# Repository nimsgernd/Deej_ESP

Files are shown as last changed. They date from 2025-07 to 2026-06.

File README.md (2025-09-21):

# Deej Fork by Daniel Nimsgern

Original deej project (description below) by omriharel

After this project sat idle for so long due to budget reasons I have decided to revive it. The main changes I am looking at are a custom PCB and a switch to using an ESP32 for ease of use and adding wireless capabilities.

The desired feature list is:
- 6 Slide potentiometers
- 6 Mute buttons (Cherry MX Green Switches)
- 2 Rotary potentiometers with switches
- 8 LED mute indicators
- 12 Slide poentiometer indicators
- 4 SPI 128x64 OLED displays

Ideas for a Rev2:
- Li-Ion battery powered (maybe 18650 or pouch cell)

# deej

deej is an **open-source hardware volume mixer** for Windows and Linux PCs. It lets you use real-life sliders (like a DJ!) to **seamlessly control the volumes of different apps** (such as your music player, the game you're playing and your voice chat session) without having to stop what you're doing.

**Join the [deej Discord server](https://discord.gg/nf88NJu) if you need help or have any questions!**



> **_New:_** [work-in-progress deej FAQ](./docs/faq/faq.md)!

deej consists of a [lightweight desktop client](#features) written in Go, and an Arduino-based hardware setup that's simple and cheap to build. [**Check out some versions built by members of our community!**](./community.md)

**[Download the latest release](https://github.com/omriharel/deej/releases/latest) | [Video demonstration](https://youtu.be/VoByJ4USMr8) | [Build video by Tech Always](https://youtu.be/x2yXbFiiAeI)**

deej

> _**Psst!** [No 3D printer? No problem!](./assets/build-shoebox.jpg)_ You can build deej on some cardboard, a shoebox or even a breadboard :)

## Table of contents

- [Deej Fork by Daniel Nimsgern](#deej-fork-by-daniel-nimsgern)
- [deej](#deej)
  - [Table of contents](#table-of-contents)
  - [Features](#features)
  - [How it works](#how-it-works)
    - [Hardware](#hardware)
      - [Schematic](#schematic)
    - [Software](#software)
  - [Slider mapping (configuration)](#slider-mapping-configuration)
  - [Build your own!](#build-your-own)
    - [FAQ](#faq)
    - [Build video](#build-video)
    - [Bill of Materials](#bill-of-materials)
    - [Thingiverse collection](#thingiverse-collection)
    - [Build procedure](#build-procedure)
  - [How to run](#how-to-run)
    - [Requirements](#requirements)
      - [Windows](#windows)
      - [Linux](#linux)
    - [Download and installation](#download-and-installation)
    - [Building from source](#building-from-source)
  - [Community](#community)
    - [Donations](#donations)
    - [Contributing](#contributing)
  - [License](#license)

## Features

deej is written in Go and [distributed](https://github.com/omriharel/deej/releases/latest) as a portable (no installer needed) executable.

- Bind apps to different sliders
  - Bind multiple apps per slider (i.e. one slider for all your games)
  - Bind the master channel
  - Bind "system sounds" (on Windows)
  - Bind specific audio devices by name (on Windows)
  - Bind currently active app (on Windows)
  - Bind all other unassigned apps
- Control your microphone's input level
- Lightweight desktop client, consuming around 10MB of memory
- Runs from your system tray
- Helpful notifications to let you know if something isn't working

> **Looking for the older Python version?** It's no longer maintained, but you can always find it in the [`legacy-python` branch](https://github.com/omriharel/deej/tree/legacy-python).

## How it works

### Hardware

- The sliders are connected to 5 (or as many as you like) analog pins on an Arduino Nano/Uno board. They're powered from the board's 5V output (see schematic)
- The board connects via a USB cable to the PC

#### Schematic

Hardware schematic

### Software

- The code running on the Arduino board is a [C program](./arduino/deej-5-sliders-vanilla/deej-5-sliders-vanilla.ino) constantly writing current slider values over its serial interface
- The PC runs a lightweight [Go client](./pkg/deej/cmd/main.go) in the background. This client reads the serial stream and adjusts app volumes according to the given configuration file

## Slider mapping (configuration)

deej uses a simple YAML-formatted configuration file named [`config.yaml`](./config.yaml), placed alongside the deej executable.

The config file determines which applications (and devices) are mapped to which sliders, and which parameters to use for the connection to the Arduino board, as well as other user preferences.

**This file auto-reloads when its contents are changed, so you can change application mappings on-the-fly without restarting deej.**

It looks like this:

```yaml
slider_mapping:
  0: master
  1: chrome.exe
  2: spotify.exe
  3:
    - pathofexile_x64.exe
    - rocketleague.exe
  4: discord.exe

# set this to true if you want the controls inverted (i.e. top is 0%, bottom is 100%)
invert_sliders: false

# settings for connecting to the arduino board
com_port: COM4
baud_rate: 9600

# adjust the amount of signal noise reduction depending on your hardware quality
# supported values are "low" (excellent hardware), "default" (regular hardware) or "high" (bad, noisy hardware)
noise_reduction: default
```

- `master` is a special option to control the master volume of the system _(uses the default playback device)_
- `mic` is a special option to control your microphone's input level _(uses the default recording device)_
- `deej.unmapped` is a special option to control all apps that aren't bound to any slider ("everything else")
- On Windows, `deej.current` is a special option to control whichever app is currently in focus
- On Windows, you can specify a device's full name, i.e. `Speakers (Realtek High Definition Audio)`, to bind that device's level to a slider. This doesn't conflict with the default `master` and `mic` options, and works for both input and output devices.
  - Be sure to use the full device name, as seen in the menu that comes up when left-clicking the speaker icon in the tray menu
- `system` is a special option on Windows to control the "System sounds" volume in the Windows mixer
- All names are case-**in**sensitive, meaning both `chrome.exe` and `CHROME.exe` will work
- You can create groups of process names (using a list) to either:
    - control more than one app with a single slider
    - choose whichever process in the group that's currently running (i.e. to have one slider control any game you're playing)

## Build your own!

Building deej is very simple. You only need a few relatively cheap parts - it's an excellent starter project (and my first Arduino project, personally). Remember that if you need any help or have a question that's not answered here, you can always [join the deej Discord server](https://discord.gg/nf88NJu).

Build deej for yourself, or as an awesome gift for your gaming buddies!

### FAQ

I've started a highly focused effort of writing a proper FAQ page for deej, covering many basic and advanced topics.

It is still _very much a work-in-progress_, but I'm happy to [share it in its current state](./docs/faq/faq.md) in hopes that it at least covers some questions you might have.

FAQ feedback in our [community Discord](https://discord.gg/nf88NJu) is strongly encouraged :)

### Build video

In case you prefer watching to reading, Charles from the [**Tech Always**](https://www.youtube.com/c/TechAlways) YouTube channel has made [**a fantastic video**](https://youtu.be/x2yXbFiiAeI) that covers the basics of building deej for yourself, including parts, costs, assembly and software. I highly recommend checking it out!

### Bill of Materials

- An Arduino Nano, Pro Micro or Uno board
  - I officially recommend using a Nano or a Pro Micro for their smaller form-factor, friendlier USB connectors and more analog pins. Plus they're cheaper
  - You can also use any other development board that has a Serial over USB interface
- A few slider potentiometers, up to your number of free analog pins (the cheaper ones cost around 1-2 USD each, and come with a standard 10K Ohm variable resistor. These _should_ work just fine for this project)
  - **Important:** make sure to get **linear** sliders, not logarithmic ones! Check the product description
  - You can also use circular knobs if you like
- Some wires
- Any kind of box to hold everything together. **You don't need a 3D printer for this project!** It works fantastically with just a piece of cardboard or a shoebox. That being said, if you do have one, read on...

### Thingiverse collection

With many different 3D-printed designs being added to our [community showcase](./community.md), it felt right to gather all of them in a Thingiverse collection for you to browse. If you have access to a 3D printer, feel free to use one of the designs in your build.

**[Visit our community-created design collection on Thingiverse!](https://thingiverse.com/omriharel/collections/deej)**

> You can also [submit your own](https://discord.gg/nf88NJu) design to be added to the collection. Regardless, if you do upload your design to Thingiverse, _please add a `deej` tag to it so that others can find it more easily_.

### Build procedure

- Connect everything according to the [schematic](#schematic)
- Test with a multimeter to be sure your sliders are hooked up correctly
- Flash the Arduino chip with the sketch in [`arduino\deej-5-sliders-vanilla`](./arduino/deej-5-sliders-vanilla/deej-5-sliders-vanilla.ino)
  - _Important:_ If you have more or less than 5 sliders, you must edit the sketch to match what you have
- After flashing, check the serial monitor. You should see a constant stream of values separated by a pipe (`|`) character, e.g. `0|240|1023|0|483`
  - When you move a slider, its corresponding value should move between 0 and 1023
- Congratulations, you're now ready to run the deej executable!

## How to run

### Requirements

#### Windows

- Windows. That's it

#### Linux

- Install `libgtk-3-dev`, `libappindicator3-dev` and `libwebkit2gtk-4.0-dev` for system tray support. Pre-built Linux binaries aren't currently released, so you'll need to [build from source](#building-from-source). If there's demand for pre-built binaries, please [let me know](https://discord.gg/nf88NJu)!

### Download and installation

- Head over to the [releases page](https://github.com/omriharel/deej/releases) and download the [latest version](https://github.com/omriharel/deej/releases/latest)'s executable and configuration file (`deej.exe` and `config.yaml`)
- Place them in the same directory anywhere on your machine
- (Optional, on Windows) Create a shortcut to `deej.exe` and copy it to `%APPDATA%\Microsoft\Windows\Start Menu\Programs\Startup` to have deej run on boot

### Building from source

If you'd rather not download a compiled executable, or want to extend deej or modify it to your needs, feel free to clone the repository and build it yourself. All you need is a Go 1.14 (or above) environment on your machine. If you go this route, make sure to check out the [developer scripts](./pkg/deej/scripts).

Like other Go packages, you can also use the `go get` tool: `go get -u github.com/omriharel/deej`. Please note that the package code now resides in the `pkg/deej` directory, and needs to be imported from there if used inside another project.

If you need any help with this, please [join our Discord server](https://discord.gg/nf88NJu).

## Community



deej is a relatively new project, but a vibrant and awesome community is rapidly growing around it. Come hang out with us in the [deej Discord server](https://discord.gg/nf88NJu), or check out a whole bunch of cool and creative builds made by our members in the [community showcase](./community.md).

The server is also a great place to ask questions, suggest features or report bugs (but of course, feel free to use GitHub if you prefer).

### Donations

If you love deej and want to show your support for this project, you can do so using the link below. Please don't feel obligated to donate - building the project and telling your friends about it goes a very long way! Thank you very much.



### Contributing

Please see [`docs/CONTRIBUTING.md`](./docs/CONTRIBUTING.md).

## License

deej is released under the [MIT license](./LICENSE).

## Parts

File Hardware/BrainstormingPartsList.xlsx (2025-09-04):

Part Name | Part ID | Qt. | Price | Sum | Octopart Link
Murata 0.1uF Capacitor | GCJ188R71H104KA12D | 18.00 | $0.12 | $2.16 | https://octopart.com/gcj188r71h104ka12d-murata-20842003
Murata 1uF Capacitor | GCM188R71E105KA64D | 1.00 | $0.19 | $0.19 | https://octopart.com/gcm188r71e105ka64d-murata-18909256
Murata 22uF Capacitor | GRM188R61A226ME15D | 1.00 | $0.11 | $0.11 | https://octopart.com/grm188r61a226me15d-murata-39203794
Murata 10uF Capacitor | GRM188D71A106MA73D | 2.00 | $0.26 | $0.52 | https://octopart.com/grm188d71a106ma73d-murata-26982325
Vishay 0.1uF Polarized Capacitor | 293D104X0035A2TE3 | 16.00 | $0.41 | $6.56 | https://octopart.com/293d104x0035a2te3-vishay-42464905
STM ESD Diode | ESDA25P35-1U1M | 1.00 | $0.37 | $0.37 | https://octopart.com/esda25p35-1u1m-stmicroelectronics-75302699
STM ESD Diode | ESDALC6V1-1U2 | 16.00 | $0.25 | $4.00 | https://octopart.com/esdalc6v1-1u2-stmicroelectronics-11912330
Vishay Red LED | VLMS1300-GS08 | 1.00 | $0.21 | $0.21 | https://octopart.com/vlms1300-gs08-vishay-21709201
ARGBW LED | IN-PI55QATPRPGPBPW-40 | 14.00 | $0.74 | $10.36 | https://octopart.com/in-pi55qatprpgpbpw-40-inolux-96300409
Vishay Orange LED | VLMO1300-GS08 | 2.00 | $0.22 | $0.44 | https://octopart.com/vlmo1300-gs08-vishay-21709200
Onsemi 100V 0.2A Rectifier Diode | MMSD4148T1G | 8.00 | $0.10 | $0.80 | https://octopart.com/mmsd4148t1g-onsemi-331798
Vishay Green LED | VLMTG1300-GS08 | 1.00 | $0.34 | $0.34 | https://octopart.com/vlmtg1300-gs08-vishay-21709202
GCT USB C | USB4085-GF-A | 1.00 | $0.88 | $0.88 | https://octopart.com/usb4085-gf-a-global+connector+technology-94773699
100mm 10k Slide Potentiameter w/ LED | Bourns PTL01-15R0-103B1 | 6.00 | $6.17 | $37.02 | https://octopart.com/ptl01-15r0-103b1-bourns-77838499
TE Connectivity 10K Ohm Resistor | 1614881-1 | 9.00 | $0.18 | $1.62 | https://octopart.com/1614881-1-te+connectivity-40125137
Panasonic 5.1K Ohm Resistor | ERJ-3EKF5101V | 2.00 | $0.10 | $0.20 | https://octopart.com/erj-3ekf5101v-panasonic-55421801
Panasonic 200 Ohm Resistor | ERJ-PA3F2000V | 1.00 | $0.12 | $0.12 | https://octopart.com/erj-pa3f2000v-panasonic-51302339
Panasonic 499 Ohm Resistor | ERJ-3EKF4990V | 2.00 | $0.10 | $0.20 | https://octopart.com/erj-3ekf4990v-panasonic-55421795
TE Connectivity 100 Ohm Resistor | 1622828-1 | 8.00 | $0.10 | $0.80 | https://octopart.com/1622828-1-te+connectivity-41187673
TE Connectivity 1K Ohm Resistor | 6-1879336-2 | 8.00 | $0.10 | $0.80 | https://octopart.com/6-1879336-2-te+connectivity-42430722
TE Connectivity 10 Ohm Resistor | CRGH0603J10R | 1.00 | $0.10 | $0.10 | https://octopart.com/crgh0603j10r-te+connectivity-24382088
TE Connectivity SMD Push Switch | 1437566-3 | 1.00 | $0.14 | $0.14 | https://octopart.com/1437566-3-te+connectivity-40512141
Cherry MX Green Mechanical Switch Kit | DMX1A-F1NA-1A | 1.00 | $15.99 | $15.99 | https://www.amazon.com/Cherry-Switch-Mechanical-Keyboard-Switches/dp/B0CXTP79HR?th=1
STM USB Choke and ESD Filter | ECMF02-2AMX6 | 1.00 | $0.41 | $0.41 | https://octopart.com/ecmf02-2amx6-stmicroelectronics-44353078
ESP32-S3 | ESP32-S3-MINI-1U-N8 | 1.00 | $5.28 | $5.28 | https://octopart.com/esp32-s3-mini-1u-n8-espressif+systems-129194335
TI 5V to 3.3V 5A LDO | LMS1585ACS-3.3/NOPB | 1.00 | $3.57 | $3.57 | https://octopart.com/lms1585acs-3.3%2Fnopb-texas+instruments-24815787
10k Rotary Poteniometer w/ push switch | Bourns 39LA-1PB-103 | 2.00 | $18.89 | $37.78 | https://octopart.com/39la-1pb-103-bourns-578549
Quad-Schmitt Trigger | TI SN74HCS126DR | 2.00 | $0.22 | $0.44 | https://octopart.com/sn74hcs126dr-texas+instruments-110195206
128x64 OLED | Adafruit 938 | 4.00 | $17.50 | $70.00 | https://octopart.com/938-adafruit+industries-32979003
Preci-Dip Male Connector 1x8 | 350-80-108-00-001101 | 5.00 | $1.12 | $5.60 | https://octopart.com/350-80-108-00-001101-preci-dip-23717904
Preci-Dip Female Connector 1x8 | 801-87-008-10-012101 | 4.00 | $1.11 | $4.44 | https://octopart.com/801-87-008-10-012101-preci-dip-23373227
Harwin 8mm Thredded Standoff | R30-1000802 | 16.00 | $0.27 | $4.32 | https://octopart.com/r30-1000802-harwin-792462
Kilo International Metal Knob | OEJL-90-4-6 | 2.00 | $12.05 | $24.10 | https://octopart.com/oejl-90-4-6-kilo+international-573308
 |  | Total |  | $239.87

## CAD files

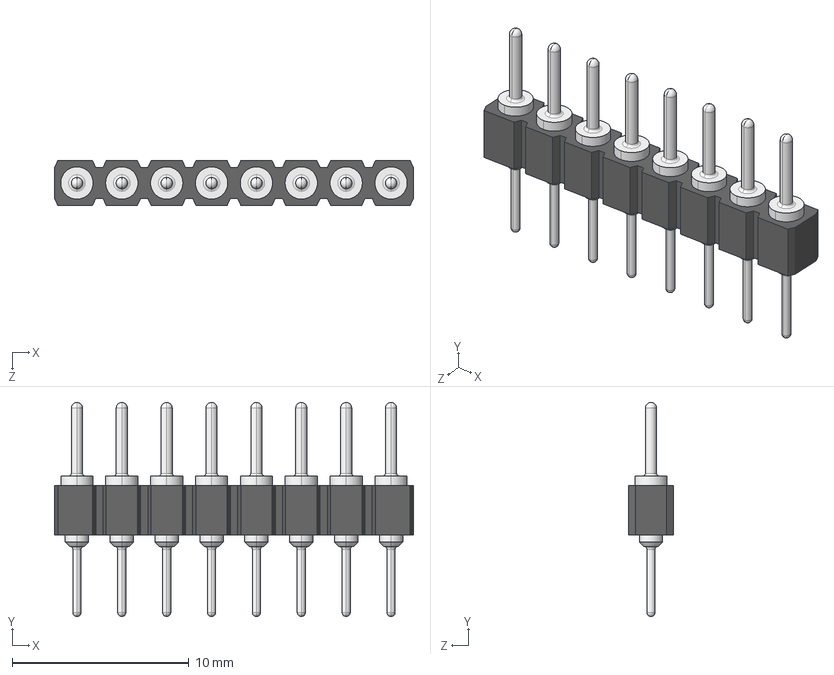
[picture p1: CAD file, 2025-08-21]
Hardware/Deej_ESP_PCB/3D_Models/350-80-108-00-001101.stp
20.3 x 12.1 x 2.54 mm

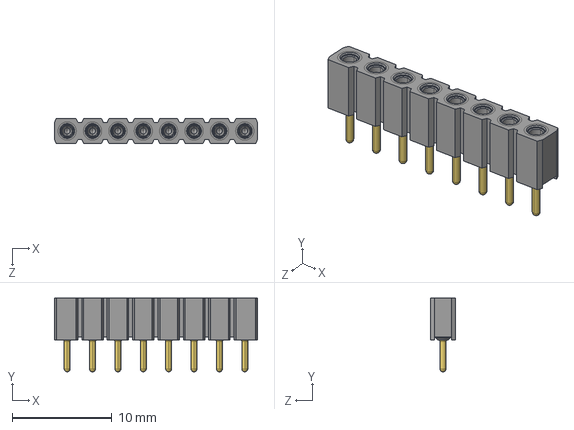
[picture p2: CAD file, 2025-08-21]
Hardware/Deej_ESP_PCB/3D_Models/801-87-008-10-012101.stp
20.3 x 7.38 x 2.54 mm

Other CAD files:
Hardware/Enclosure/Deej_Enclosure.FCStd

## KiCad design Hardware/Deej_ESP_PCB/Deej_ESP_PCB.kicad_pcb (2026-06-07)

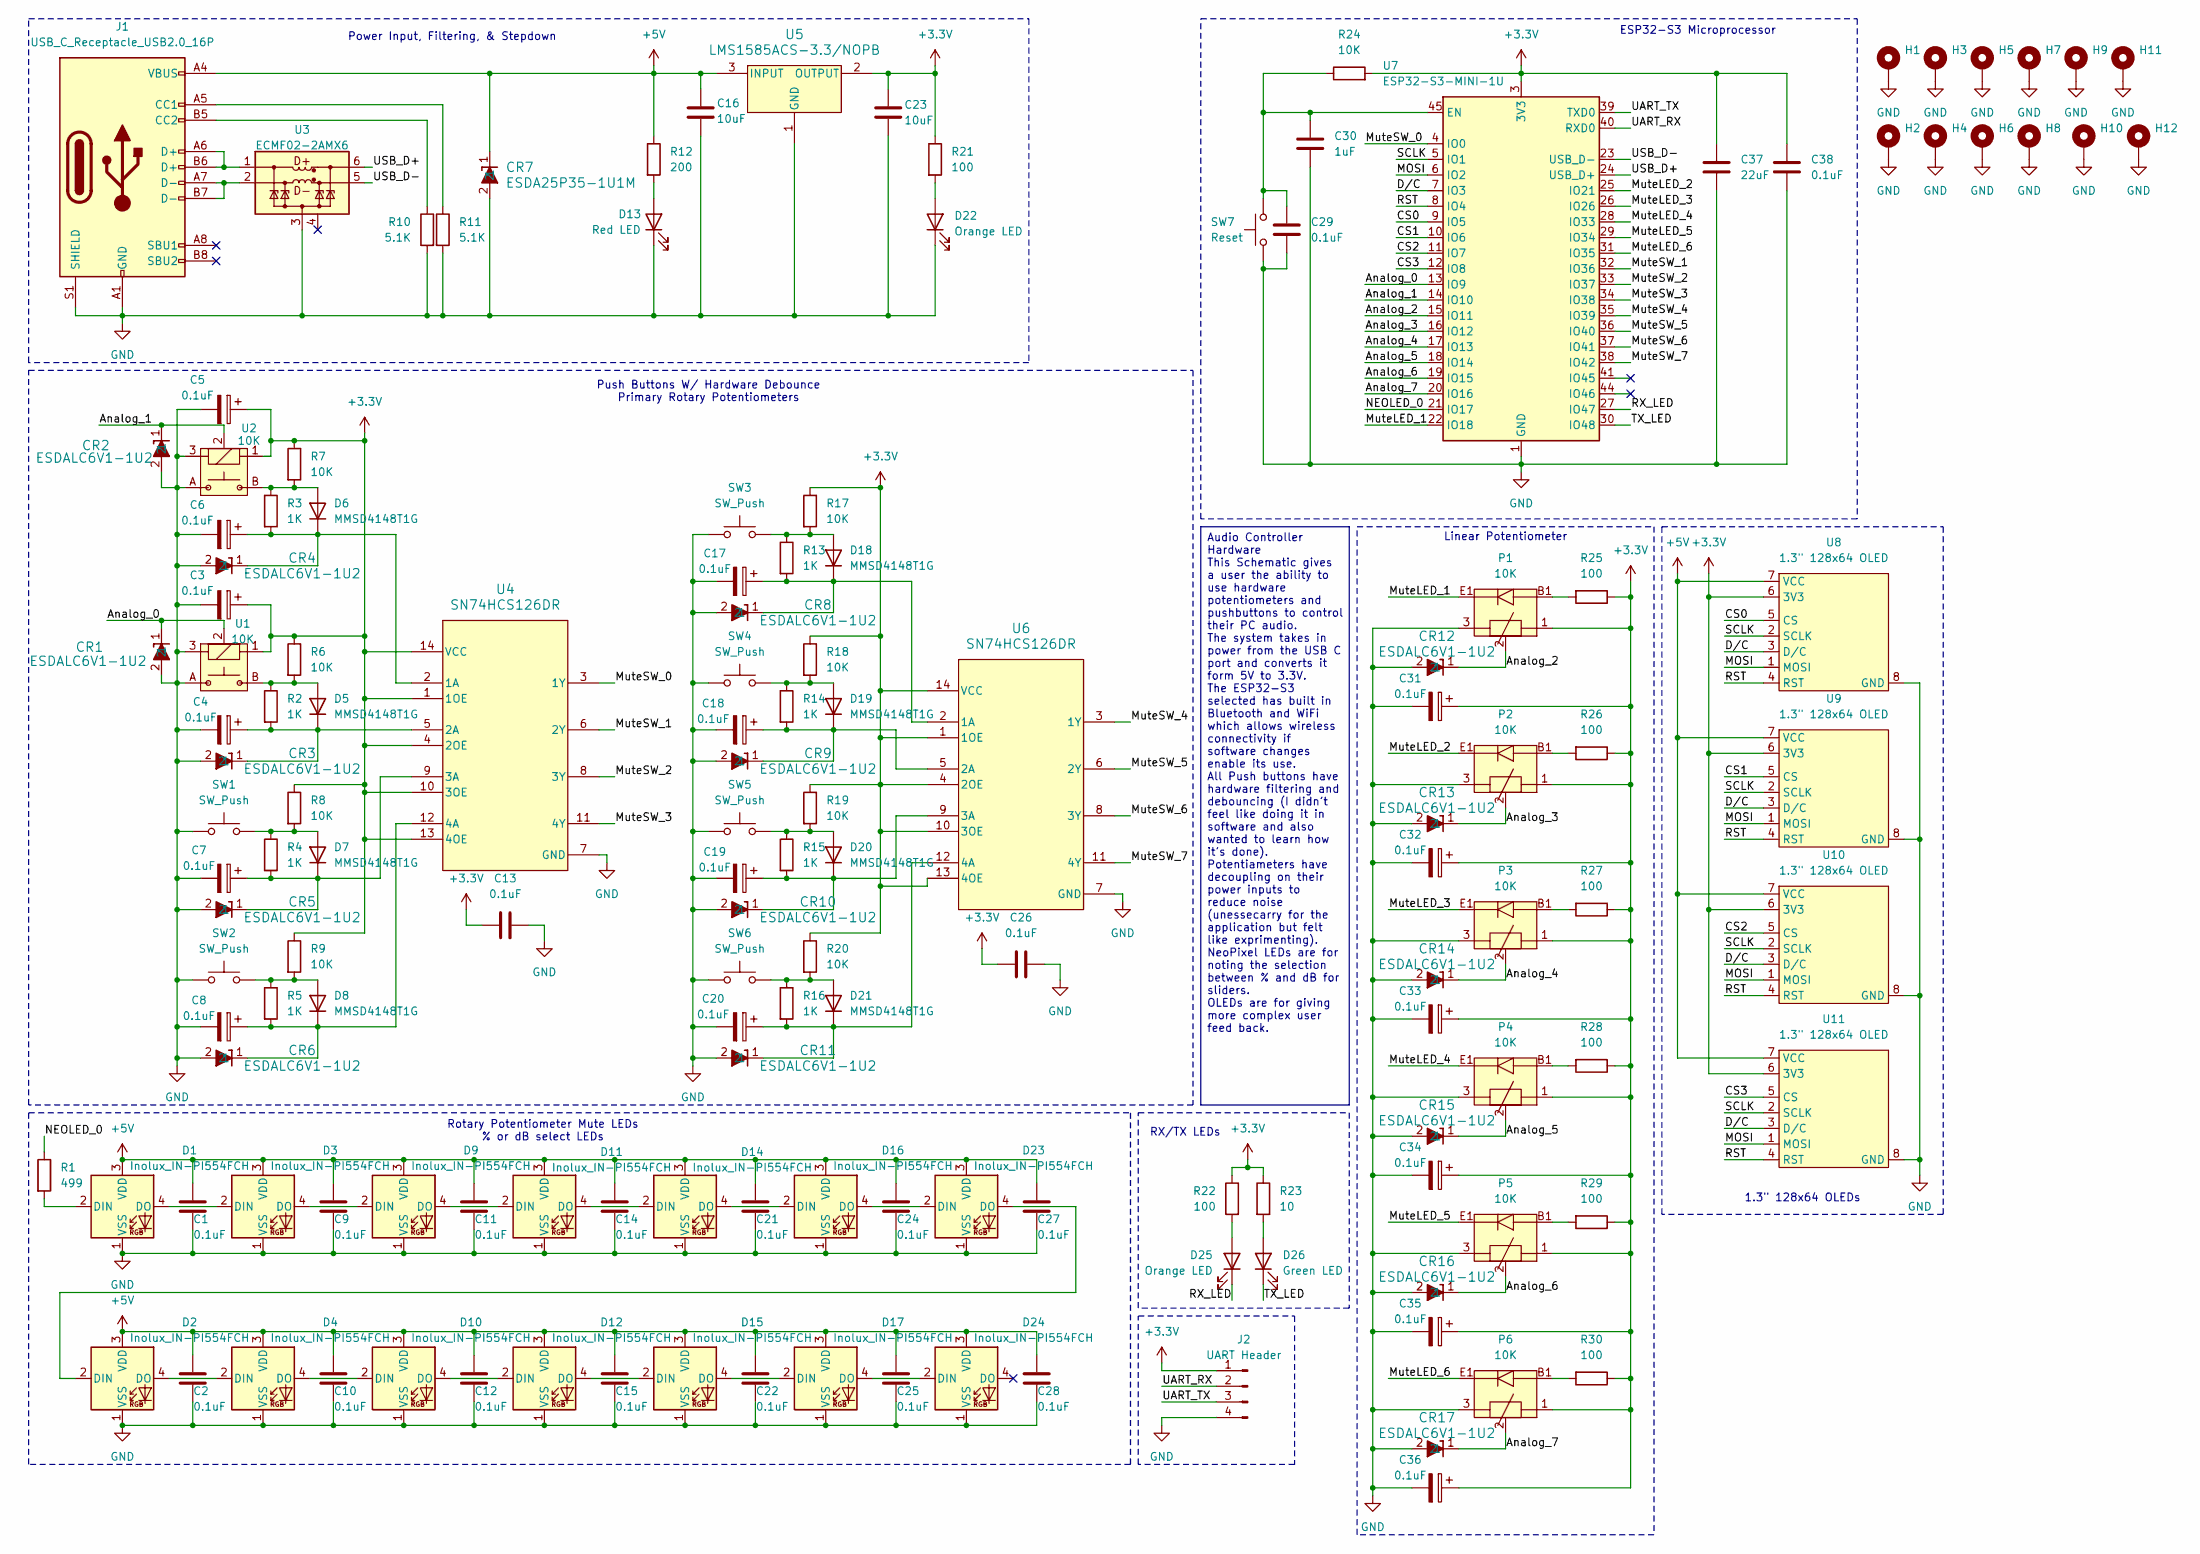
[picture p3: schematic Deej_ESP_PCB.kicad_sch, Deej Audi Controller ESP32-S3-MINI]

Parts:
C1, C2, C9, C10, C11, C12, C13, C14, C15, C21, C22, C24, C25, C26, C27, C28, C29, C38: 0.1uF; C_0603_1608Metric_Pad1.08x0.95mm_HandSolder
C3, C4, C5, C6, C7, C8, C17, C18, C19, C20, C31, C32, C33, C34, C35, C36: 0.1uF; CP_EIA-3216-18_Kemet-A_HandSolder
C16, C23: 10uF; C_0603_1608Metric_Pad1.08x0.95mm_HandSolder
C30: 1uF; C_0603_1608Metric_Pad1.08x0.95mm_HandSolder
C37: 22uF; C_0603_1608Metric_Pad1.08x0.95mm_HandSolder
CR1, CR2, CR3, CR4, CR5, CR6, CR8, CR9, CR10, CR11, CR12, CR13, CR14, CR15, CR16, CR17: ESDALC6V1-1U2; DIODE_ESDALC6V1-1U2_STM
CR7: ESDA25P35-1U1M; QFN1610_STM
D1, D2, D3, D4, D9, D10, D11, D12, D14, D15, D16, D17, D23, D24: Inolux_IN-PI554FCH; LED_Inolux_IN-PI554FCH_PLCC4_5.0x5.0mm_P3.2mm
D5, D6, D7, D8, D18, D19, D20, D21: MMSD4148T1G; D_SOD-123
D13: Red LED; LED_0603_1608Metric_Pad1.05x0.95mm_HandSolder
D22, D25: Orange LED; LED_0603_1608Metric_Pad1.05x0.95mm_HandSolder
D26: Green LED; LED_0603_1608Metric_Pad1.05x0.95mm_HandSolder
H1, H3, H5, H7, H9: MountingHole_3.2mm_M3_Pad
H2, H4, H6, H8, H10, H11, H12: MountingHole_Pad; MountingHole_3.2mm_M3_Pad
J1: USB_C_Receptacle_USB2.0_16P; USB_C_Receptacle_GCT_USB4085
J2: UART Header; PinHeader_1x04_P2.54mm_Vertical
P1, P2, P3, P4, P5, P6: 10K; PTL0115R0103B1
R1: 499; C_0603_1608Metric_Pad1.08x0.95mm_HandSolder
R2, R3, R4, R5, R13, R14, R15, R16: 1K; C_0603_1608Metric_Pad1.08x0.95mm_HandSolder
R6, R7, R8, R9, R17, R18, R19, R20, R24: 10K; C_0603_1608Metric_Pad1.08x0.95mm_HandSolder
R10, R11: 5.1K; C_0603_1608Metric_Pad1.08x0.95mm_HandSolder
R12: 200; C_0603_1608Metric_Pad1.08x0.95mm_HandSolder
R21, R22, R25, R26, R27, R28, R29, R30: 100; C_0603_1608Metric_Pad1.08x0.95mm_HandSolder
R23: 10; C_0603_1608Metric_Pad1.08x0.95mm_HandSolder
SW1, SW2, SW3, SW4, SW5, SW6: SW_Push; SW_Cherry_MX_PCB
SW7: Reset; SWITCH_FSMSM_TYC
U1, U2: 10K; 39LA-1PB-103
U3: ECMF02-2AMX6; QFN-6L_STM
U4, U6: SN74HCS126DR; D0014A-IPC_A
U5: LMS1585ACS-3.3/NOPB; KTT0003B
U7: ESP32-S3-MINI-1U; ESP32S3MINI1UN8
U8, U9, U10, U11: 1.3" 128x64 OLED; Adafruit_1_3_OLED

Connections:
+3.3V: C3.1, C5.1, C13.2, C23.1, C26.2, C31.1, C32.1, C33.1, C34.1, C35.1, C36.1, C37.1, C38.1, J2.1, P1.1, P2.1, P3.1, P4.1, P5.1, P6.1, R6.1, R7.1, R8.1, R9.1, R17.1, R18.1, R19.1, R20.1, R21.1, R22.1, R23.1, R24.2, R25.1, R26.1, R27.1, R28.1, R29.1, R30.1, U1.1, U2.1, U4.1 (1OE), U4.4 (2OE), U4.10 (3OE), U4.13 (4OE), U4.14 (VCC), U5.2 (OUTPUT), U5.4 (OUTPUT), U6.1 (1OE), U6.4 (2OE), U6.10 (3OE), U6.13 (4OE), U6.14 (VCC), U7.3 (3V3), U8.6 (3V3), U9.6 (3V3), U10.6 (3V3), U11.6 (3V3)
+5V: C1.1, C2.1, C9.1, C10.1, C11.1, C12.1, C14.1, C15.1, C16.1, C21.1, C22.1, C24.1, C25.1, C27.1, C28.1, CR7.1, D1.3 (VDD), D2.3 (VDD), D3.3 (VDD), D4.3 (VDD), D9.3 (VDD), D10.3 (VDD), D11.3 (VDD), D12.3 (VDD), D14.3 (VDD), D15.3 (VDD), D16.3 (VDD), D17.3 (VDD), D23.3 (VDD), D24.3 (VDD), J1.A4 (VBUS), J1.A9 (VBUS), J1.B4 (VBUS), J1.B9 (VBUS), R12.1, U5.3 (INPUT), U8.7 (VCC), U9.7 (VCC), U10.7 (VCC), U11.7 (VCC)
/Analog_0: CR1.1, U1.2, U7.13 (IO9)
/Analog_1: CR2.1, U2.2, U7.14 (IO10)
/Analog_2: CR12.1, P1.2, U7.15 (IO11)
/Analog_3: CR13.1, P2.2, U7.16 (IO12)
/Analog_4: CR14.1, P3.2, U7.17 (IO13)
/Analog_5: CR15.1, P4.2, U7.18 (IO14)
/Analog_6: CR16.1, P5.2, U7.19 (IO15)
/Analog_7: CR17.1, P6.2, U7.20 (IO16)
/CS0: U7.9 (IO5), U8.5 (CS)
/CS1: U7.10 (IO6), U9.5 (CS)
/CS2: U7.11 (IO7), U10.5 (CS)
/CS3: U7.12 (IO8), U11.5 (CS)
/D/C: U7.7 (IO3), U8.3 (D/C), U9.3 (D/C), U10.3 (D/C), U11.3 (D/C)
/MOSI: U7.6 (IO2), U8.1 (MOSI), U9.1 (MOSI), U10.1 (MOSI), U11.1 (MOSI)
/MuteLED_1: P1.E1, U7.22 (IO18)
/MuteLED_2: P2.E1, U7.25 (IO21)
/MuteLED_3: P3.E1, U7.26 (IO26)
/MuteLED_4: P4.E1, U7.28 (IO33)
/MuteLED_5: P5.E1, U7.29 (IO34)
/MuteLED_6: P6.E1, U7.31 (IO35)
/MuteSW_0: U4.3 (1Y), U7.4 (IO0)
/MuteSW_1: U4.6 (2Y), U7.32 (IO36)
/MuteSW_2: U4.8 (3Y), U7.33 (IO37)
/MuteSW_3: U4.11 (4Y), U7.34 (IO38)
/MuteSW_4: U6.3 (1Y), U7.35 (IO39)
/MuteSW_5: U6.6 (2Y), U7.36 (IO40)
/MuteSW_6: U6.8 (3Y), U7.37 (IO41)
/MuteSW_7: U6.11 (4Y), U7.38 (IO42)
/NEOLED_0: R1.1, U7.21 (IO17)
/RST: U7.8 (IO4), U8.4 (RST), U9.4 (RST), U10.4 (RST), U11.4 (RST)
/RX_LED: D25.1 (K), U7.27 (IO47)
/SCLK: U7.5 (IO1), U8.2 (SCLK), U9.2 (SCLK), U10.2 (SCLK), U11.2 (SCLK)
/TX_LED: D26.1 (K), U7.30 (IO48)
/UART_RX: J2.2, U7.40 (RXD0)
/UART_TX: J2.3, U7.39 (TXD0)
/USB_D+: U3.6 (D+_out), U7.24 (USB_D+)
/USB_D-: U3.5 (D-_out), U7.23 (USB_D-)
GND: C1.2, C2.2, C3.2, C4.2, C5.2, C6.2, C7.2, C8.2, C9.2, C10.2, C11.2, C12.2, C13.1, C14.2, C15.2, C16.2, C17.2, C18.2, C19.2, C20.2, C21.2, C22.2, C23.2, C24.2, C25.2, C26.1, C27.2, C28.2, C29.2, C30.2, C31.2, C32.2, C33.2, C34.2, C35.2, C36.2, C37.2, C38.2, CR1.2, CR2.2, CR3.2, CR4.2, CR5.2, CR6.2, CR7.2, CR8.2, CR9.2, CR10.2, CR11.2, CR12.2, CR13.2, CR14.2, CR15.2, CR16.2, CR17.2, D1.1 (VSS), D2.1 (VSS), D3.1 (VSS), D4.1 (VSS), D9.1 (VSS), D10.1 (VSS), D11.1 (VSS), D12.1 (VSS), D13.1 (K), D14.1 (VSS), D15.1 (VSS), D16.1 (VSS), D17.1 (VSS), D22.1 (K), D23.1 (VSS), D24.1 (VSS), H1.1, H2.1, H3.1, H4.1, H5.1, H6.1, H7.1, H8.1, H9.1, H10.1, H11.1, H12.1, J1.A1 (GND), J1.A12 (GND), J1.B1 (GND), J1.B12 (GND), J1.S1 (SHIELD), J2.4, P1.3, P2.3, P3.3, P4.3, P5.3, P6.3, R10.2, R11.2, SW1.1, SW2.1, SW3.1, SW4.1, SW5.1, SW6.1, SW7.1, U1.3, U1.A, U2.3, U2.A, U3.3 (GND), U4.7 (GND), U5.1 (GND), U6.7 (GND), U7.1 (GND), U7.2 (GND), U7.42 (GND), U7.43 (GND), U7.46 (GND), U7.47 (GND), U7.48 (GND), U7.49 (GND), U7.50 (GND), U7.51 (GND), U7.52 (GND), U7.53 (GND), U7.54 (GND), U7.55 (GND), U7.56 (GND), U7.57 (GND), U7.58 (GND), U7.59 (GND), U7.60 (GND), U7.61 (GND), U7.62 (GND), U7.63 (GND), U7.64 (GND), U7.65 (GND), U7.66 (GND), U7.67 (GND), U7.68 (GND), U7.69 (GND), U7.70 (GND), U7.71 (GND), U7.72 (GND), U7.73 (GND), U8.8 (GND), U9.8 (GND), U10.8 (GND), U11.8 (GND)
unnamed: D1.2 (DIN), R1.2
unnamed: D1.4 (DO), D3.2 (DIN)
unnamed: D2.2 (DIN), D23.4 (DO)
unnamed: D2.4 (DO), D4.2 (DIN)
unnamed: D3.4 (DO), D9.2 (DIN)
unnamed: D5.2 (A), R2.1, R6.2, U1.B
unnamed: C4.1, CR3.1, D5.1 (K), R2.2, U4.5 (2A)
unnamed: D6.2 (A), R3.1, R7.2, U2.B
unnamed: C6.1, CR4.1, D6.1 (K), R3.2, U4.2 (1A)
unnamed: D7.2 (A), R4.1, R8.2, SW1.2
unnamed: C7.1, CR5.1, D7.1 (K), R4.2, U4.9 (3A)
unnamed: D8.2 (A), R5.1, R9.2, SW2.2
unnamed: C8.1, CR6.1, D8.1 (K), R5.2, U4.12 (4A)
unnamed: D4.4 (DO), D10.2 (DIN)
unnamed: D10.4 (DO), D12.2 (DIN)
unnamed: D9.4 (DO), D11.2 (DIN)
unnamed: D11.4 (DO), D14.2 (DIN)
unnamed: D12.4 (DO), D15.2 (DIN)
unnamed: D13.2 (A), R12.2
unnamed: D14.4 (DO), D16.2 (DIN)
unnamed: D15.4 (DO), D17.2 (DIN)
unnamed: D16.4 (DO), D23.2 (DIN)
unnamed: D17.4 (DO), D24.2 (DIN)
unnamed: D18.2 (A), R13.1, R17.2, SW3.2
unnamed: C17.1, CR8.1, D18.1 (K), R13.2, U6.2 (1A)
unnamed: D19.2 (A), R14.1, R18.2, SW4.2
unnamed: C18.1, CR9.1, D19.1 (K), R14.2, U6.5 (2A)
unnamed: D20.2 (A), R15.1, R19.2, SW5.2
unnamed: C19.1, CR10.1, D20.1 (K), R15.2, U6.9 (3A)
unnamed: D21.2 (A), R16.1, R20.2, SW6.2
unnamed: C20.1, CR11.1, D21.1 (K), R16.2, U6.12 (4A)
unnamed: D22.2 (A), R21.2
unnamed: D25.2 (A), R22.2
unnamed: D26.2 (A), R23.2
unnamed: J1.A5 (CC1), R11.1
unnamed: J1.B5 (CC2), R10.1
unnamed: P1.B1, R25.2
unnamed: P2.B1, R26.2
unnamed: P3.B1, R27.2
unnamed: P4.B1, R28.2
unnamed: P5.B1, R29.2
unnamed: P6.B1, R30.2
unnamed: J1.A6 (D+), J1.B6 (D+), U3.1 (D+_in)
unnamed: J1.A7 (D-), J1.B7 (D-), U3.2 (D-_in)
unnamed: C29.1, C30.1, R24.1, SW7.2, U7.45 (EN)

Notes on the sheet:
Push Buttons W/ Hardware Debounce Primary Rotary Potentiometers
Linear Potentiometer
Rotary Potentiometer Mute LEDs % or dB select LEDs
RX/TX LEDs
1.3" 128x64 OLEDs
ESP32-S3 Microprocessor
Power Input, Filtering, & Stepdown
Audio Controller Hardware This Schematic gives a user the ability to use hardware potentiometers and pushbuttons to control their PC audio. The system takes in power from the USB C port and converts it form 5V to 3.3V. The ESP32-S3 selected has built in Bluetooth and WiFi which allows wireless conn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

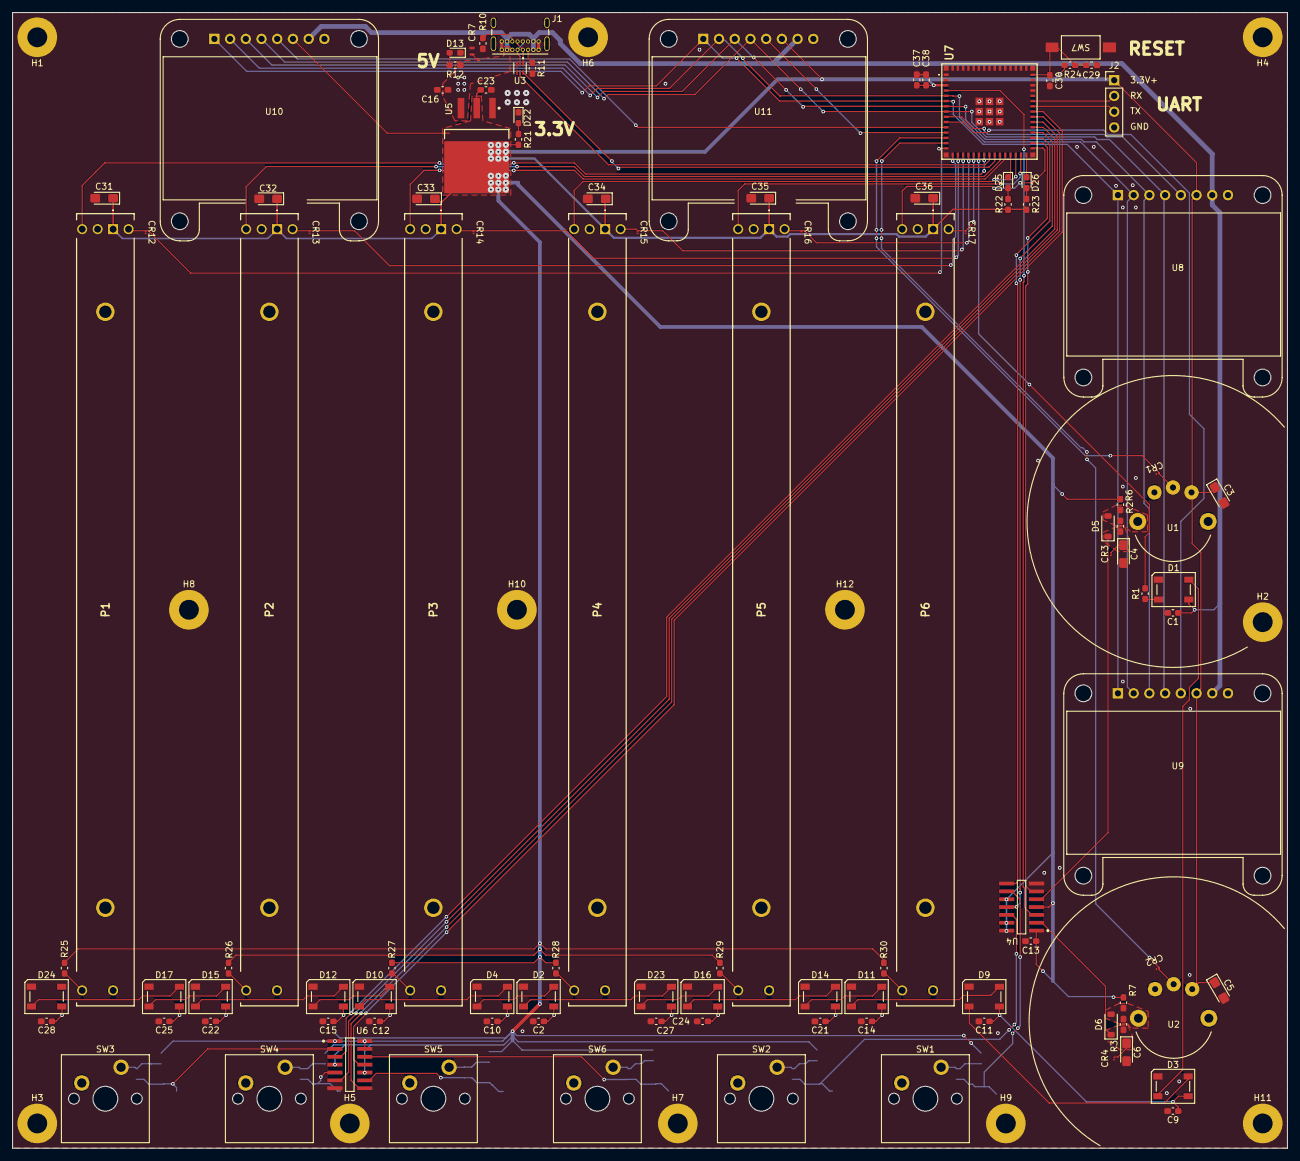
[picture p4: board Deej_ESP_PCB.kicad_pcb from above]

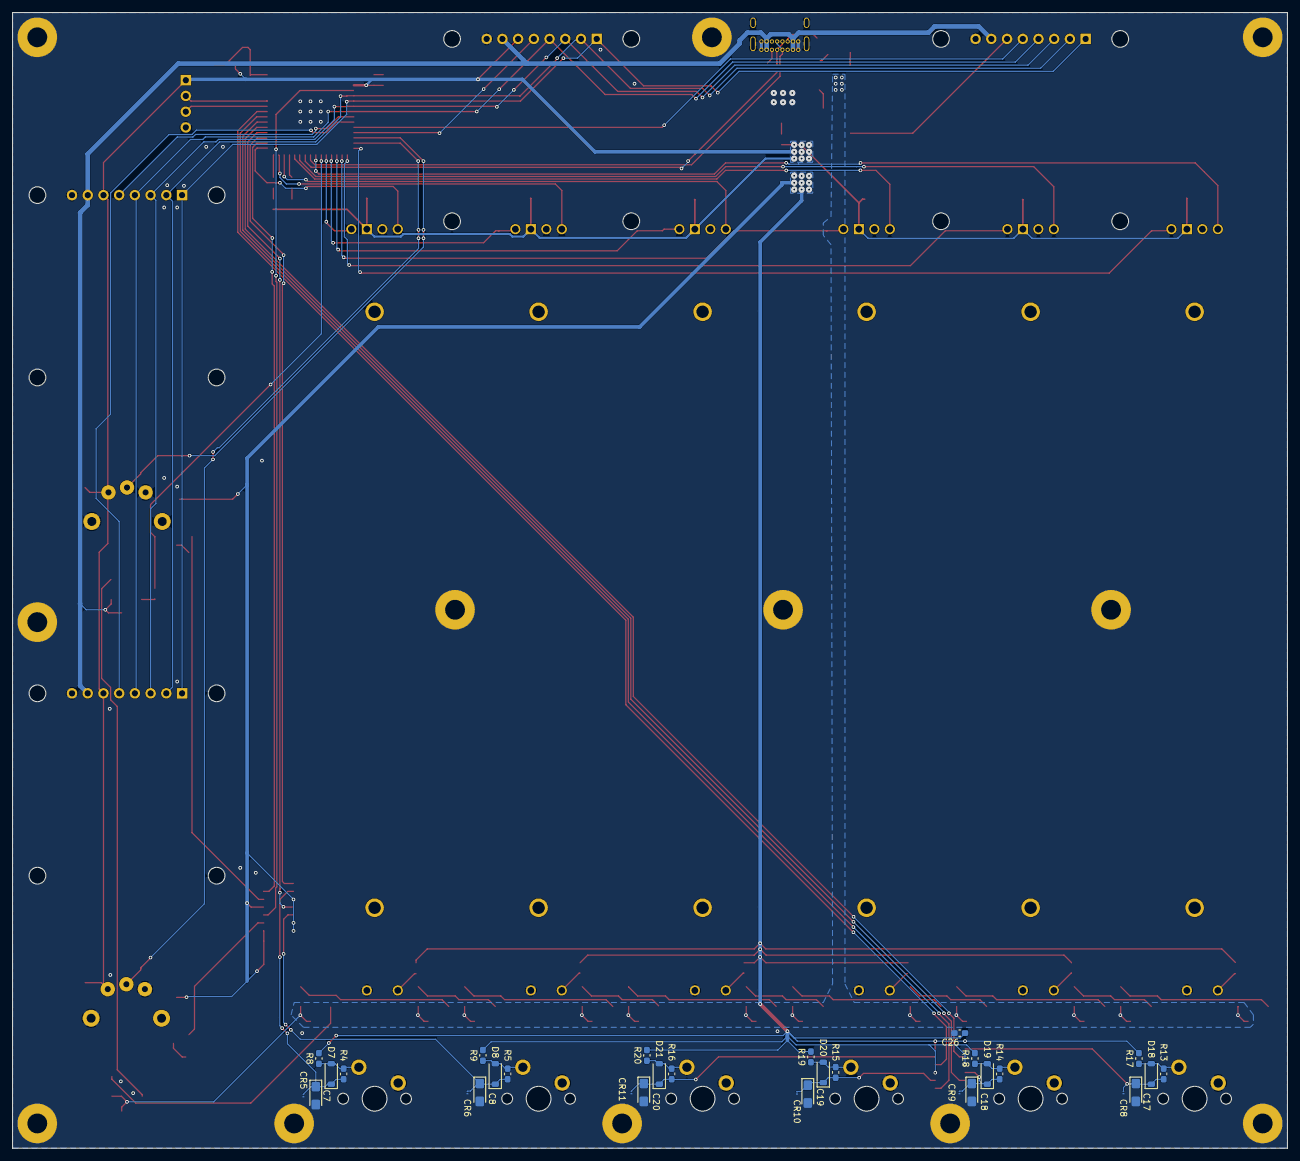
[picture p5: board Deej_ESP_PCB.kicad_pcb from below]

Board: 2 copper layers, 206.0 x 183.5 mm, 149 parts (31 on the bottom side), 85 nets.

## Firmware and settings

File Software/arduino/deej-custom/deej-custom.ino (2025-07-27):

/*******************************************************************************
**************************Setup and Primary Program*****************************
* | @file       :	deej-custom.ino
* |	@version    :	V1.0
* | @date       :	2024-03-26
* | @author     : Daniel Nimsgern <nimsgernd>
* | @brief      :	Hardware Audio controller
* |             : 10 Sliders | 2 Knobs | 12 Mute Buttons | 16 Macro Buttons |
* |             : 12 LED Mute indicators | 4 0.96" Monochrome SPI OLED Modules
*******************************************************************************/

/*******************************************************************************
 * Includes
 ******************************************************************************/

#include <SPI.h>
#include <Wire.h>
#include <Keyboard.h>
#include <Adafruit_GFX.h>
#include <Adafruit_SSD1306.h>

/*******************************************************************************
 * Variables
 ******************************************************************************/

/* Analog Inputs */
#define NUM_POTS      (int) 12
  /*****************
   | Master : A0
   | Mic    : A1
   | Faders : A2-A11
   *****************/
static const int analogPotInputs[NUM_POTS] = {A0, A1, A2, A3, A4, A5, A6, A7,
                                              A8, A9, A10, A11};

/* Digital Inputs */
#define NUM_MUTE_BUTTONS  (int) 12
#define NUM_MACRO_BUTTONS (int) 16
  /**************************
   | Master Mute : 68
   | Mic Mute    : 69
   | Fader Mutes : 6-15
   | Macro 1-16  : 22-52 even
   **************************/
static const int digitalMuteButtonInputs[NUM_MUTE_BUTTONS] = {68, 69, 6, 7,
                                                              8, 9, 10, 11, 12,
                                                              13, 14, 15};
static const int digitalMacroButtonInputs[NUM_MACRO_BUTTONS] = {22, 24, 26, 28,
                                                                30, 32, 34, 36,
                                                                38, 40, 42, 44,
                                                                46, 48, 50, 52};

/* LED Pins */
#define NUM_LEDS      (int) 12
  /********************
   | Master : 23
   | Mic    : 25
   | Faders : 27-45 odd
   ********************/
static const int digitalLEDOutputs[NUM_LEDS] = {23, 25, 27, 29, 31, 33, 35, 37,
                                                39, 41, 43, 45};

/* OLED Values */
#define SCREEN_WIDTH  (int) 128 // OLED display width, in pixels
#define SCREEN_HEIGHT (int) 64 // OLED display height, in pixels

#define NUM_DISPLAYS  (int) 4
  /******************
   | OLED Reset : 0
   | OLED DC    : 1
   | OLED CS    : 2-5
   ******************/
#define OLED_RESET    (int) 0
#define OLED_DC       (int) 1
static const int oledCS[NUM_DISPLAYS] = {2, 3, 4, 5};

/* Program Data */
static int analogPotValues[NUM_POTS];
static bool digitalMuteButtonValues[NUM_MUTE_BUTTONS];
static Adafruit_SSD1306 display[NUM_DISPLAYS];

/*******************************************************************************
 * Initialize I/O and Serial Connections
 ******************************************************************************/

/**********************************************************
  @brief setup
         Initializes all necessary pins and systems.
**********************************************************/
void setup() {
  /* Serial Connection */
  Serial.begin(115200);

  /* Analog Inputs */
  analogReadResolution(12);
  for (int i = 0; i < NUM_POTS; i++)
  {
    pinMode(analogPotInputs[i], INPUT);
  }

  /* Button Inputs */
  if (NUM_POTS != NUM_MUTE_BUTTONS)
  {
    Serial.println("Number of potentiameters is not equal to the number of mute buttons. This may have unexpeced results.\n");
  }
  for (int i = 0; i < NUM_MUTE_BUTTONS; i++)
  {
    pinMode(digitalMuteButtonInputs[i], INPUT_PULLUP);
    attachInterrupt(digitalPinToInterrupt(digitalMuteButtonInputs[i]),
                    muteButtonPress, FALLING);
  }

  Keyboard.begin(KeyboardLayout_en_US);
  for (int i = 0; i < NUM_MACRO_BUTTONS; i++)
  {
    pinMode(digitalMacroButtonInputs[i], INPUT_PULLUP);
    attachInterrupt(digitalPinToInterrupt(digitalMuteButtonInputs[i]),
                    macroButtonPress, FALLING);
  }

  /* LED Outputs */
  if (NUM_MUTE_BUTTONS != NUM_LEDS)
  {
    Serial.println("Number of LEDs is not equal to the number of mute buttons. This may have unexpeced results.\n");
  }
  for (int i = 0; i < NUM_LEDS; i++)
  {
    pinMode(digitalLEDOutputs[i], OUTPUT);
  }

  /* OLED Connections */
  for (int i = 0; i < NUM_DISPLAYS; i++)
  {
    display[i] = (SCREEN_WIDTH, SCREEN_HEIGHT, &SPI, OLED_DC, OLED_RESET,
                  oledCS[i]);
    if(!display[i].begin(SSD1306_SWITCHCAPVCC))
    {
      Serial.println(F("SSD1306 allocation failed"));
      for(;;); // Don't proceed, loop forever
    }
  }
}

/*******************************************************************************
 * Main Program
 ******************************************************************************/

/**********************************************************
  @brief loop
         Loops through main process.
**********************************************************/
void loop() {
  updateValues();
  updateLEDs();
  sendValues(); // Actually send data (all the time)
  // printValues(); // For debug
  delay(10);
}

/*******************************************************************************
 * Functon Definitions
 ******************************************************************************/

/**********************************************************
  @brief updateValues
         Reads the analog pins to update the values.
**********************************************************/
void updateValues() {
  for (int i = 0; i < NUM_POTS; i++) {
     if (digitalMuteButtonValues[i])
     {
      analogPotValues[i] = 0;
     }
     else
     {
      analogPotValues[i] = analogRead(analogPotInputs[i]);
     }
  }
}

/**********************************************************
  @brief updateLEDs
         Sets LED states based on the mute button states.
**********************************************************/
void updateLEDs()
{
  for (int i = 0; i < NUM_LEDS; i++)
  {
    if(digitalMuteButtonValues[i])
    {
      digitalWrite(digitalLEDOutputs[i], HIGH);
    }
    else
    {
      digitalWrite(digitalLEDOutputs[i], LOW);
    }
  }
}

/**********************************************************
  @brief sendValues
         Sends a string containing all read values to
         serial.
**********************************************************/
void sendValues() {
  String builtString = String("");

  for (int i = 0; i < NUM_POTS; i++) {
    builtString += String((int)analogPotValues[i]);

    if (i < NUM_POTS - 1) {
      builtString += String("|");
    }
  }
  
  Serial.println(builtString);
}

/**********************************************************
  @brief printValues
         Prints the read values to the serial console.
**********************************************************/
void printValues() {
  for (int i = 0; i < NUM_POTS; i++) {
    String printedString = String("Slider #") + String(i + 1) + String(": ") +
                           String(analogPotValues[i]) + String(" mV");
    Serial.write(printedString.c_str());

    if (i < NUM_POTS - 1) {
      Serial.write(" | ");
    } else {
      Serial.write("\n");
    }
  }
}

/*******************************************************************************
 * Interrupts
 ******************************************************************************/

/**********************************************************
  @brief muteButtonPress
         Interrupt to record when a mute button has been
         pressed.
**********************************************************/
void muteButtonPress()
{
  for (int i = 0; i < NUM_MUTE_BUTTONS; i++)
  {
    if (digitalRead(digitalMuteButtonInputs[i]) == LOW)
    {
      digitalMuteButtonValues[i] != digitalMuteButtonValues[i];
    }
  }
}

/**********************************************************
  @brief macroButtonPress
         Interrupt to record when a macro button has been
         pressed.
**********************************************************/
void macroButtonPress()
{
  int buttonNumber;
  for (int i = 0; i < NUM_MACRO_BUTTONS; i++)
  {
    if(digitalRead(digitalMacroButtonInputs[i]) == LOW)
    {
      switch(i)
      {
        // Add aditional macro stwitch statments as desired;
        default :
        {
          Serial.write("No macro mapped to this button.\n");
        }
      }
    }
  }
}

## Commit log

2025-07-27 Initial KiCAD project set up and decided to go with the ESP32 S3 Mini 1U N8 as the MCU.
    [Deej_ESP_PCB.kicad_pcb, Deej_ESP_PCB.kicad_sch]
2025-08-01 Started brainstorming for major components. So far decided on MCU, LEDs, OLED displays, slide potentiameters, and GPIO expanders. Based on the price I am considering changing some of the quantities..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
    [BrainstormingPartsList.xlsx]
2025-08-05 Adding components to the part library
    [Deej_ESP_PCB.kicad_pcb, Deej_ESP_PCB.kicad_sch]
2025-08-05 Chose Cherry MX Green Switches for the mute buttons for that good decisive click
    [BrainstormingPartsList.xlsx]
2025-08-07 Figured out componentes for hardware debouncing and making sure all components have 3D models for when it comes time to make an enclosure
    [BrainstormingPartsList.xlsx, Deej_ESP_PCB.kicad_sch, ESP32-S3-MINI-1U-N8.STEP]
2025-08-09 3D File, ESD, and Old File Clean up
    * Added the 3D files for the rotary potentiometer with switch.
    * Started adding ESD diodes to components the user will touch regularly.
    * Removed old files that won't be used.
    [BrainstormingPartsList.xlsx, Deej_ESP_PCB.kicad_sch, ESP32-S3-MINI-1U-N8.STEP]
2025-08-10 USB Supporting Hardware, 3D Models, BOM Updates
    * Added supporting hardware for the USB C connector
    * Ensured all current components have 3D models
    * Updated the BOM with components for the USB connector
    [BrainstormingPartsList.xlsx, Deej_ESP_PCB.kicad_sch]
2025-08-11 Added Footprints and 3D Files
    - Added the proper footprint and 3D file for the ESP32
    - Added the footprint and 3D file for the USB choke/ESD so the project
    doesn't rely on an external library
    - Added the power step down circuit and LED indicators
    - Added a user LED for program status
    - Made a "Good Enough for Government Work" symbol and footprint for
    the Bourns rotary potentiometer I want to use while I wait for
    SamacSys
    - Updated the BOM
    [BrainstormingPartsList.xlsx, Deej_ESP_PCB.kicad_sch]
2025-08-19 Converted From KiCAD Nightly to Stable
    I realized that I had been using the nightly version instead of the
    stable release which became an issue when my nightly broke and all
    more recent nightly builds have had issues building.
    - The main change was just changing the version and generator version
    in the schematic and PCB files.
    - The schematic file had some pin and power settings that were not
    compatable in the stable build.
    - The PCB file had a few settings that were not compatable.
    - I did not manually edit the project file so I think that was
    automatically adjusted.
    [Deej_ESP_PCB.kicad_pcb, Deej_ESP_PCB.kicad_sch]
2025-08-19 Delete Hardware/Deej_ESP_PCB/Deej_ESP_PCB.kicad_prl
    This auto generated project view preferences file should not have been pushed. Not quite sure why the .gitignore didn't work.
2025-08-20 Migrated Project Footprints to KiCAD Stable
    - I updated the project footprints to be compatable with KiCAD stable
    release.
    - I replaced the footprint for the slide potentiometer.
    - I corrected the Adafruit display in the BOM sheet since I swapped it
    out a few commits ago.
    [BrainstormingPartsList.xlsx, Deej_ESP_PCB.kicad_sch]
2025-08-21 Still dealing with KiCAD Migration issues
    - Had to spend way too much time fixing the libraries.
    - Adjusted the Adafruit 1.3" OLED footprint 3D model to use a lower
    profile pin headder.
    - Added the lower profile pins to the BOM.
    - Went through some of the ERC and fixed some issues (most relating to
    the library issues mentioned above).
    [350-80-108-00-001101.stp, 801-87-008-10-012101.stp, BrainstormingPartsList.xlsx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]
2025-08-23 Finished Schemtic 🎉 For now...
    - Added supporting hardware for the ESP32-S3 (decoupling capacitors and
    reset button)
    - Added hardware support for a UART conntection (hoping I won't need to
    use it but you never know)
    - Fixed all ERC issues
    - Replaced the original 11mm stand offs with 8mm stand offs for the
    Adafruit displays
    [BrainstormingPartsList.xlsx, Deej_ESP_PCB.kicad_sch]
2025-08-31 Synced the KiCAD BOM and my handmade BOM
    [BrainstormingPartsList.xlsx, Deej_ESP_PCB.kicad_sch]
2025-09-04 Started PCB Layout Added Mounting Holes and Knobs
    - Started doing PCB layout. I have an idea of large component placement
    and therefore overall board size but still working out finalizing
    them.
    - Added platted mounting holes to the board mostly for support since
    most of this board is user interfaces I expect there to be a good
    amount of force applied to the sliders, buttons, and knobs.
    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
    [BrainstormingPartsList.xlsx, Deej_ESP_PCB.kicad_pcb, Deej_ESP_PCB.kicad_sch]
2025-09-16 All Components Placed and OSH Park Rules Set.
    - I have placed all of the components and I am looking at starting trace
    layout.
    - I have also set the rules and board stack up specifications for OSH
    Park to ensure thaat the design is as similr to how the final product
    will be.
    [Deej_ESP_PCB.kicad_pcb, Deej_ESP_PCB.kicad_sch]
2025-11-08 Getting Back into it
    I had gotten a little more busy and wasn't able to get back to it.
    - Routed some more power traces
    - Routed the analog signals for the slide potentiometers
    [Deej_ESP_PCB.kicad_pcb, Deej_Enclosure.FCStd]
2025-11-19 More Power Routing and NEO Pixel LED Routing
    - Added more +3.3V voltage routing
    - Added some signaling for the NEO Pixel LEDs
    TODO: Other LED traces and analog dials
    [Deej_ESP_PCB.kicad_pcb, Deej_ESP_PCB.kicad_sch]
2025-12-05 Finished Running Traces, On to DRC Fixes
    - I believe I finished running the traces to get everything connected
    KiCAD shows one more air wire but that seems like a visual isses since
    I can confirm it is connected.
    - Next I will be starting on fixing the 94 DRC ERRORs. A lot of them
    seems really simple on first glance so I'm not worried about those but
    there are a few errors involving clearances and manufacturing minimums.
    [Deej_ESP_PCB.kicad_pcb, Deej_ESP_PCB.kicad_sch]
2026-06-07 -Trace routing 'done' ... until I find another issue -Fixing DRC errors and warnings
    [Deej_ESP_PCB.kicad_pcb, Deej_ESP_PCB.kicad_sch]
